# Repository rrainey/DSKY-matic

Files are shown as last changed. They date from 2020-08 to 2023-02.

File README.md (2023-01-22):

# The DSKY-matic Project
A Functioning Apollo DSKY Replica - October 2021

## Introduction

The Apollo Guidance Compuer (AGC) is one of the critical inventions that made the U.S. moon landings possible. AGC's were installed in both the Apollo Command Module and Lunar Module. MIT and NASA archives, as well as important contributions from researchers have given us a rich set of detail about how this computer was constructed.

Space and computer enthusiasts like me from all over the world have enjoyed exploring this work from the early space era.

### Why is this project called "DSKY-matic"?

Because *"Riley Rainey's Apollo Guidance Computer DSKY Replica Project"* doesn't really roll off the tongue.

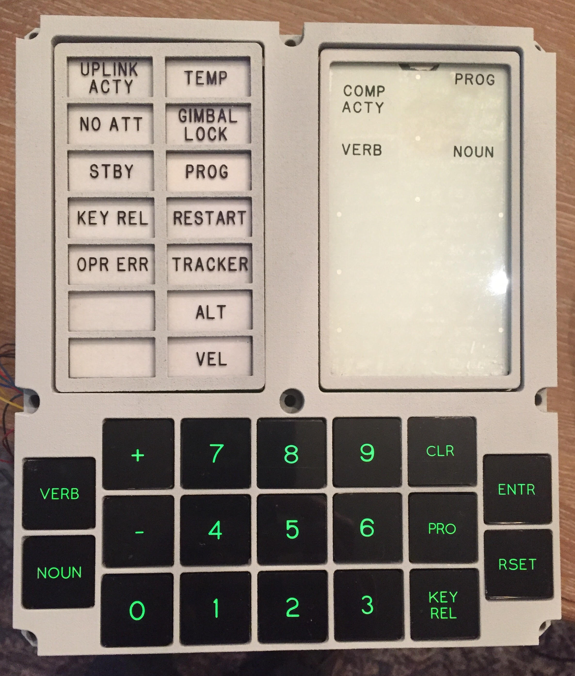
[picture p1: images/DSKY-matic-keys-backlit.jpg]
The first DSKY-matic prototype


Naming a project is often difficult. In this case it's especially hard: the Apollo Guidance Computer has inspired many replica projects. I wanted to create a replica of the DSKY that was faithful to the original look and feel. And I wanted to be able to interact with it.  I came up with **DSKY-matic** to tag it with an easy name distinguishing it from other projects.

DSKY-matic is an open project so that anyone can reproduce the work or build upon my results.

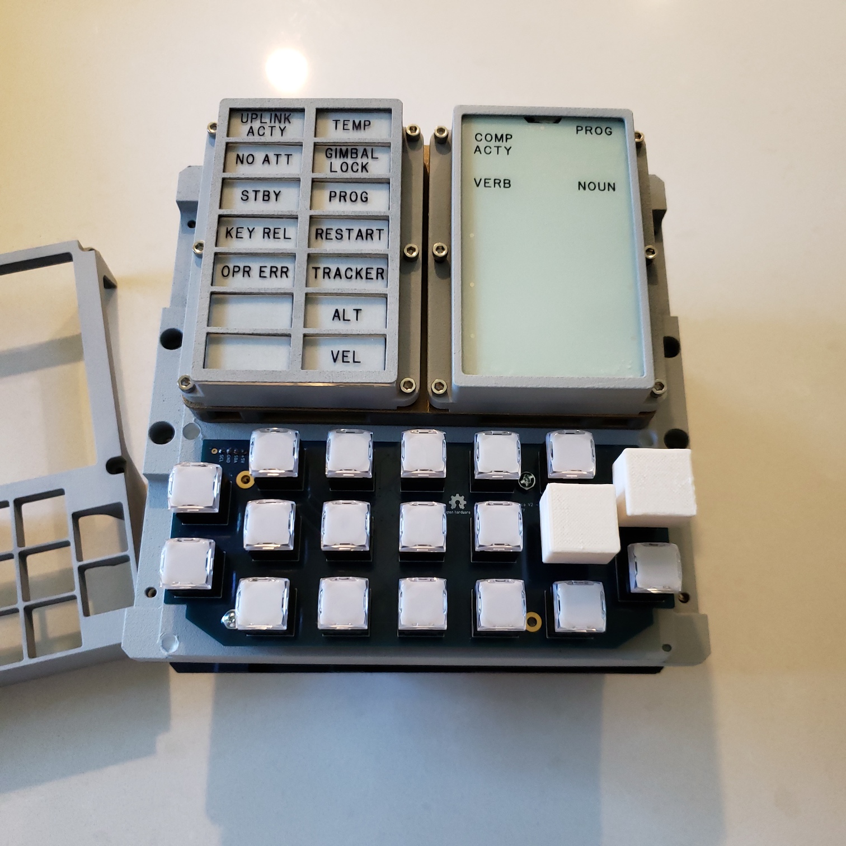
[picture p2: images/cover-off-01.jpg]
The first DSKY-matic prototype (cover off)


### Components and cloning this project

The EL or LED Displays, Alarm Panel, and Keyboard are each modular components. They are driven by a
  Raspberry Pi 4 to simulate the AGC, but each could be swapped out with equivalent redesigns. A
  Power Supply Hat mates with the Raspberry Pi 4 to distribute +5V and +3.3V power to all boards.

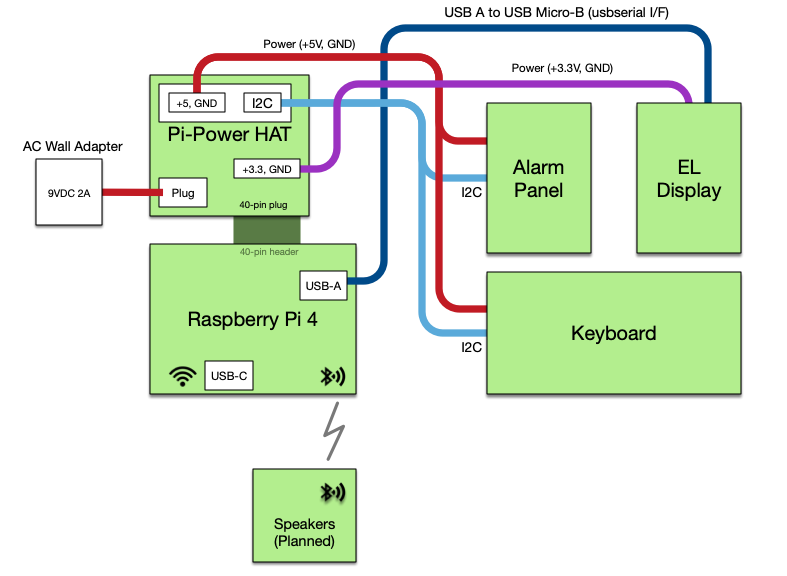
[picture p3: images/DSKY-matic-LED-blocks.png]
The first DSKY-matic prototype


You will find more information about interconnections and cabling in [this document](ASSEMBLY.md)

### Project Status

Hardware work is complete. I'm working on a distributable version of the full simulator software.

Major to-dos:

* [**complete**] adapt Virtual AGC to use these Lamp, Keyboard, and Display drivers
* [**complete**] improve the keyboard's pushbutton design - the current version is a rather clunky 3D printed design that could look much more realistic
* [**complete**] design and test an alternative to the original Electroluminescent Display module. This alternate assembly uses LEDs in place of the EL display.  It's easier to build and may be more reliable over time - if not as cool.
* [**complete**] build and test batch of the revised (current limited) EL Driver boards
* [**complete**] test fully integrated DSKY hardware and software driver configuration
* [**in progress**] Integrated AGC and spacecraft simulator software

### Cloning

The hardware and firmware for each major component is segregated into git submodules. You will need to follow some specific steps to clone the entire tree on your local machine. First, clone this repository:

        $ git clone https://github.com/rrainey/DSKY-matic.git

Go into the project folder:

        $ cd DSKY-matic

Now clone all submodules:

        $ git submodule update --init --recursive --remote

### Directory Structure

* **hardware** - 3D-printable frame components designed using Fusion 360. STEP and the original Fusion source files are provided. Hardware models used in thie replica were derived from models found in the [AGC Mechanical CAD project](https://github.com/rrainey/agc-mechanical-cad).

* **src** - software components designed to run on the project's embedded Raspberry Pi 4.  This software is a Apollo Guidance Computer virtual machine interfacing to the displays and keyboard via I2C and USB serial communications drivers.

* **DSKY-alarm-panel-replica** - definition of the Alarm Panel hardware and software assembly

* **DSKY-digital-indicator-replica** - definition an alternative to the EL Display Panel; this variant is based on LEDs

* **DSKY-keyboard-replica** - definition of the Keyboard hardware and software assembly

* **Pi-Power** - power supply hat for the Raspberry Pi 4

* **virtualagc** - Ron Burkey's Virtual AGC software; runs on the Raspberry Pi 4 in this implementation

## Arduino-based Drivers

The custom hardware boards that are part of this project all run Arduino-based firmware on ATSAMD21 processors.

### Configuring Boards

The peripheral boards for DSKY-matic run Arduino-based software. When you have a board ready for software installation, you'll use the Arduino IDE to build and install the driver onto a board. Custom DSKY-matic Arduino board definitions help with this process.

There's a few steps leading up to this installation that you'll need to follow first:

1. **Build bootloaders for each board** - these bootloaders are used to install Arduino firmware drivers on each board

```
git clone https://github.com/rrainey/uf2-samdx1
cd uf2-samdx1
make BOARD=dskydisplay_led_m0
make BOARD=dskyalarm_m0
make BOARD=dskykeyboard_m0
```

These steps will build bin and uf2 files in a `build` subfolder.

2. **Install the bootloader** - Bootloaders can be installed by following the procedure outlined in this [Adafruit article](https://learn.adafruit.com/how-to-program-samd-bootloaders). The DSKY-matic Keyboard and LED Display boards are equipped with ATSAMD JTAG/SWD connectors.  Those boards can have the bootloader installed directly using a SEGGER J-Link Edu Mini interface as described in the article.  For the Alarm board, I followed Ben's technique of cannibalizing
  the SAMD processor from a Trinket M0 to install on the board.  The advantage there is that the bootloader is already installed.  You can follow that approach as well, or connect the SWD line up directly and program via a SEGGER interface too.

3. **Install the Arduino IDE** -
Install the Arduino IDE. I'm currently using version 1.8.13.

4. **Install the Arduino board definitions** -
These must be installed in your Arduino IDE. An excellent guide to this process is described at this [Adafruit help page](https://learn.adafruit.com/add-boards-arduino-v164/setup). At the point in the steps where you are supplying "Additional Boards Manager URLs" use this URL: `https://github.com/rrainey/ArduinoCore-samd/releases/download/x1.0.0/package_rrainey_dskymatic_index.json`

5. **Connect a board via USB, Build and install the appropriate firmware driver** -- I'll add more detailed instructions here soon, but the firmware is located in the GitHub repo for each board project.

### Sound setup on the Raspberry Pi 4

There's a bit of set up required to play sound from the ALSA drivers. The aplay and
amixer commands are used here to set the volume from the command line:

<pre>
<b>$ aplay -L</b>
null
    Discard all samples (playback) or generate zero samples (capture)
pulse
    Playback/recording through the PulseAudio sound server
sysdefault:CARD=ALSA
    bcm2835 ALSA, bcm2835 ALSA
    Default Audio Device
<b>$ amixer</b>
Simple mixer control 'Master',0
    Capabilities: pvolume pswitch pswitch-joined penum
    Playback channels: Front Left - Front Right
    Limits: Playback 0 - 65536
    Mono:
    Front Left: Playback 65536 [100%] [on]
    Front Right: Playback 65536 [100%] [on]
Simple mixer control 'Capture',0
    Capabilities: cvolume cswitch cswitch-joined penum
    Capture channels: Front Left - Front Right
    Limits: Capture 0 - 65536
    Front Left: Capture 0 [0%] [on]
    Front Right: Capture 0 [0%] [on]
<b>$ amixer controls</b>
numid=4,iface=MIXER,name='Master Playback Switch'
numid=3,iface=MIXER,name='Master Playback Volume'
numid=2,iface=MIXER,name='Capture Switch'
numid=1,iface=MIXER,name='Capture Volume'
<b>$ amixer cset numid=3 50%</b>
numid=3,iface=MIXER,name='Master Playback Volume'
  ; type=INTEGER,access=rw------,values=2,min=0,max=65536,step=1
  : values=32768,32768
</pre>

### Credits

This project would not have been possible without the generous and open work of these projects:

* [The Virtual AGC Project](https://www.ibiblio.org/apollo/) -- Ron Burkey and others have worked for years to build software emulator of the AGC hardware, supporting developments tools, a collection of original NASA and MIT documents, as well as an archive of transcribed original CM and LEM programs.
* [Adafruit Industries](https://www.adafruit.com/) -- Lady Yada and others have produced a great line of hobbyist microcontrollers and supporting programming tools. They deserve your support.
* [The Raspberry Pi Foundation](https://www.raspberrypi.org/about/) -- The Raspberry Pi Foundation is a UK-based charity that is the source fabulous Linux-compatible low-cost computers.

## DSKY-matic License

Software components (everything in "./src") are licensed under the GPL v2. All other elements are covered 
under Creative Commons Attribution/Share-Alike, all text above must be included in any redistribution. See license.txt for additional details.

## My Background

My name is Riley Rainey. I'm a software developer by profession. I spent a number of years building aerospace simulations as my day job.

## Getting Support

There's no official support available, but you can [leave comments or create an issue](https://github.com/rrainey/DSKY-alarm-panel-replica/issues) in this GitHub project.

  
This work is licensed under a [Creative Commons Attribution-ShareAlike 4.0 International License](http://creativecommons.org/licenses/by-sa/4.0/).

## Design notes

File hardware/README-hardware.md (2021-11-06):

## Off-the-shelf Components

Screws, washers, and threaded inserts are used to asseble the DSKY. I have tried to stick with screws similar to those used in the original DSKY.  These will cost more, but add to the realism of the project.  I Ordered these parts from McMaster Carr.

| Description | Part Number | Qty Ordered | Qty Unit |
|---|---|:---:|---|
| Socket Head Screw 10-32 Thread Size, 1-1/2" Long, Partially Threaded | 92185A994 | 1 | Pack of 10 each |
| Retainers for 6-32 Thread Size Captive Panel Screws | 91065A640 | 1 | Pack of 25 each |
| Socket Head Captive Panel Screw 6-32 Thread Size, 3/4" Long | 95966A237 | 12 | 1 each |
| 18-8 Stainless Steel Socket Head Screw 6-32 Thread Size, 1-1/2" Long, Partially Threaded | 92196A157 | 1 | Pack of 100 each |
| 18-8 Stainless Steel Mil. Spec. Washer Passivated, Number 6 Screw Size, NAS 620-C6 | 90945A716 | 1 | Pack of 250 each |
| 18-8 Stainless Steel Mil. Spec. Washer Passivated, Number 4 Screw Size, NAS 620-C4 | 90945A711 | 1 | Pack of 500 each |
| Passivated 18-8 Stainless Steel Phillips Flat Head Screw 82 Degree Countersink, 4-40 Thread, 7/8" Long | 91771A114 | 1 | Pack of 100 each |
| 18-8 Stainless Steel Socket Head Screw 10-32 Thread Size, 1-1/2" Long, Partially Threaded | 92196A277 | 1 | Pack of 50 each |
| 18-8 Stainless Steel Socket Head Screw 6-32 Thread Size, 3/4" Long | 92196A151 | 1 | Pack of 100 each |
| 18-8 Stainless Steel Socket Head Screw 4-40 Thread Size, 3/8" Long | 92196A108 | 1 | Pack of 100 each |
| 18-8 Stainless Steel Socket Head Screw 6-32 Thread Size, 1/2" Long | 92196A148 | 1 | Pack of 100 each |
| Brass Screw-to-Expand Inserts for Plastic, 10-32 Thread Size, 1/4" Installed Length | 92395A224 | 1 | Pack of 25 each |

## Mounting Hardware Parts

Inserts are used with the two mounting base legs and the Pi mounting bracket. I install ultrasonic style inserts using a C-clamp to screw-down each insert into place.

Components can be ordered from Grainger.com:

| Part Description | Grainger SKU | Order Qty | Where Used |
|---|---|:-----:|---|
| M2.5-0.45mm Machine Screw, Pan, Phillips, Property Class 4.8 | 6GE33 |  1  | Pi Bracket (4) |
| Nylon Flat Washer, Plain FastenerFinish, Fits Bolt Sizes M3, 8 mm | 4DAZ2 |  1  | Pi Bracket (4) |
| Round, Spacer, Nylon, Black, 5mm Outside Dia., PK 10 |3ZMR2 | 1 | Pi Bracket (4) |
| Ultrasonic Insert, Tapered, Brass, M2.5 x 0.45mm Internal Thread | 1GRL4 | 1 | Pi Bracket (4) |
| Cylindrical, Socket Head Cap Screw, #8-32, Stainless Steel, 18- | 6XA72 | 1 | DSKY Base (8) |
| Ultrasonic Insert, Straight Flush, Brass, 8-32 Internal Thread Size, | 1GTL3 | 1 | DSKY Base (8) |
| Ultrasonic Insert, Tapered, Brass, 4-40 Internal Thread Size, UNC, 7/32 in Length | 1GPL4 | 1 | Front Cover (10) |
| Ultrasonic Insert, Tapered, Brass, 6-32 Internal Thread Size, UNC, 5/32 in Length | 1GML7 | 1 | Front Cover (8) |

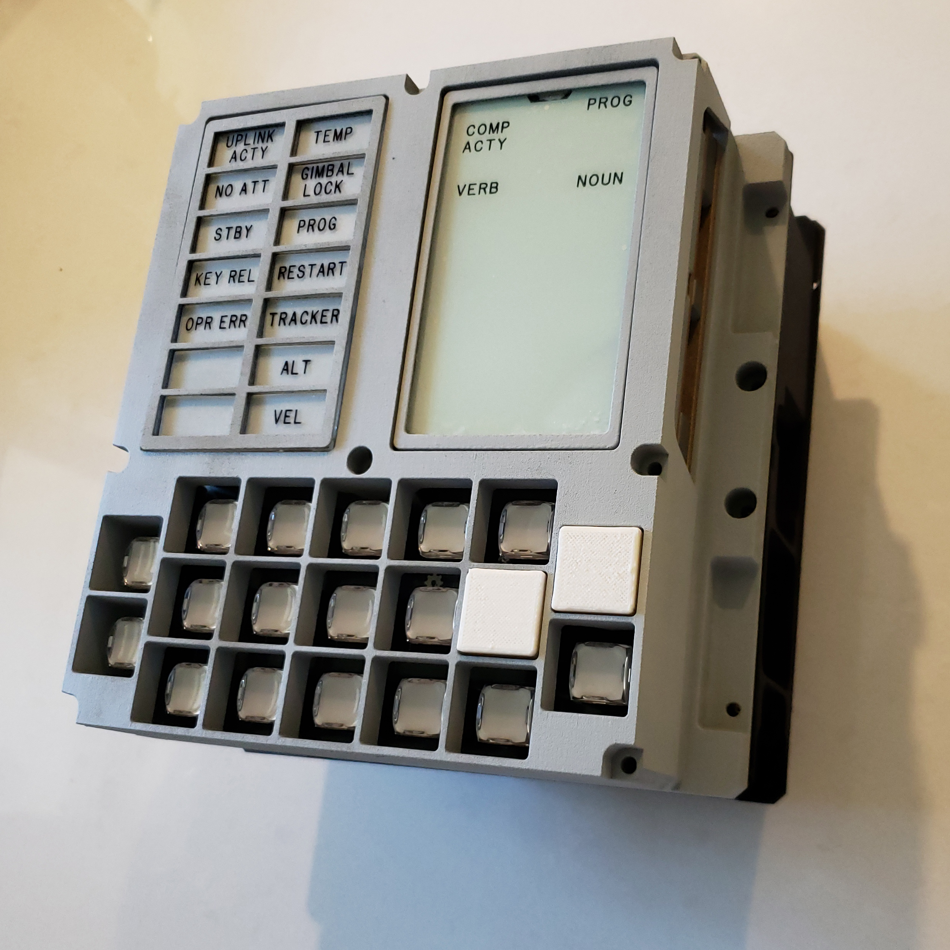
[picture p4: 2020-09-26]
images/oblique-early-large.jpg

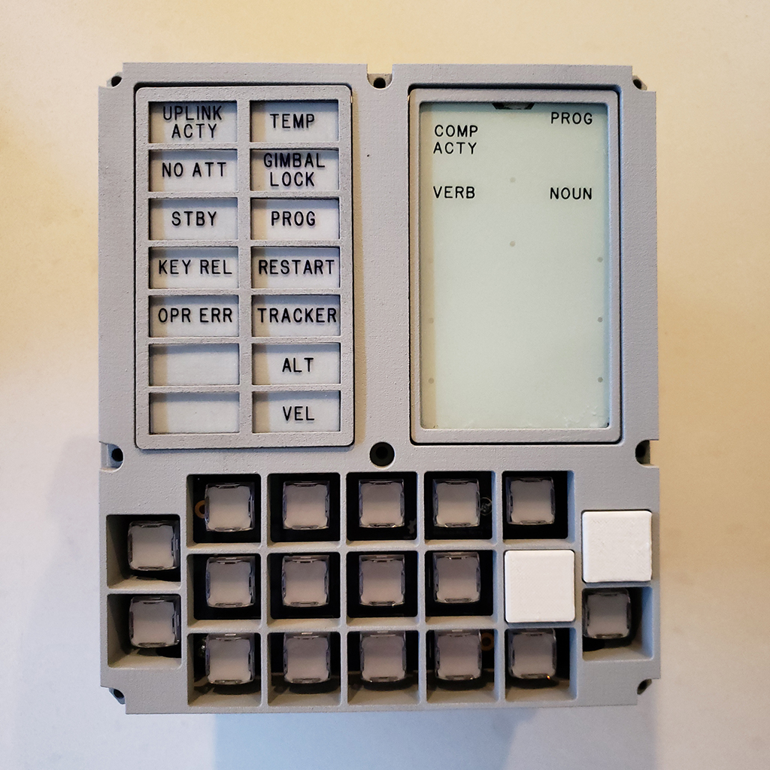
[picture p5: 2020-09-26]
images/front-early-sm.jpg

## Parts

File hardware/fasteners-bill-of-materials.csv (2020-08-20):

Quantity | Unit | Product | Description
1 | Pack of 250 | 90945A716 | 18-8 Stainless Steel Mil. Spec. Washer Passivated, Number 6 Screw Size, NAS 620-C6
1 | Pack of 50 | 92395A112 | Brass Screw-to-Expand Inserts for Plastic, 4-40 Thread Size, 0.188" Installed Length
1 | Pack of 50 | 92395A113 | Brass Screw-to-Expand Inserts for Plastic, 6-32 Thread Size, 1/4" Installed Length
1 | Pack of 25 | 92395A224 | Brass Screw-To-Expand Inserts For Plastic, 10-32 Thread Size, 1/4" Installed Length
1 | Pack of 500 | 90945A711 | 18-8 Stainless Steel Mil. Spec. Washer Passivated, Number 4 Screw Size, NAS 620-C4
1 | Pack of 25 | 91065A640 | Retainers for 6-32 Thread Size Captive Panel Screws
12 | Each | 95966A237 | Socket Head Captive Panel Screw 6-32 Thread Size, 3/4" Long
1 | Pack of 100 | 91771A114 | 18-8 Stainless Steel Phillips Flat Head Screw Passivated, 4-40 Thread Size, 7/8" Long
1 | Pack of 50 | 92196A277 | 18-8 Stainless Steel Socket Head Screw 10-32 Thread Size, 1-1/2" Long, Partially Threaded
1 | Pack of 100 | 92196A151 | 18-8 Stainless Steel Socket Head Screw 6-32 Thread Size, 3/4" Long
1 | Pack of 100 | 92196A108 | 18-8 Stainless Steel Socket Head Screw 4-40 Thread Size, 3/8" Long
1 | Pack of 100 | 92196A148 | 18-8 Stainless Steel Socket Head Screw 6-32 Thread Size, 1/2" Long

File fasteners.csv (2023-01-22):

QTY | UNIT | MCMASTER PRODUCT | DESCRIPTION | UNIT PRICE | EXTENDED PRICE
1 | Pack of 10 each | 92185A994 | Super-Corrosion-Resistant 316 Stainless Steel Socket Head Screw 10-32 Thread Size, 1-1/2" Long, Partially Threaded | 6.13 | 6.13
1 | Pack of 25 each | 91065A640 | Retainers for 6-32 Thread Size Captive Panel Screws | 14.15 | 14.15
12 | Each | 95966A237 | Socket Head Captive Panel Screw 6-32 Thread Size, 3/4" Long | 4.15 | 49.80
1 | Pack of 100 each | 92196A157 | 18-8 Stainless Steel Socket Head Screw 6-32 Thread Size, 1-1/2" Long, Partially Threaded | 17.01 | 17.01
1 | Pack of 250 each | 90945A716 | 18-8 Stainless Steel Mil. Spec. Washer Passivated, Number 6 Screw Size, NAS 620-C6 | 20.21 | 20.21
1 | Pack of 500 each | 90945A711 | 18-8 Stainless Steel Mil. Spec. Washer Passivated, Number 4 Screw Size, NAS 620-C4 | 32.50 | 32.50
1 | Pack of 100 each | 91771A114 | Passivated 18-8 Stainless Steel Phillips Flat Head Screw 82 Degree Countersink, 4-40 Thread, 7/8" Long | 7.59 | 7.59
1 | Pack of 50 each | 92196A277 | 18-8 Stainless Steel Socket Head Screw 10-32 Thread Size, 1-1/2" Long, Partially Threaded | 16.09 | 16.09
1 | Pack of 100 each | 92196A151 | 18-8 Stainless Steel Socket Head Screw 6-32 Thread Size, 3/4" Long | 9.50 | 9.50
1 | Pack of 100 each | 92196A108 | 18-8 Stainless Steel Socket Head Screw 4-40 Thread Size, 3/8" Long | 6.07 | 6.07
1 | Pack of 100 each | 92196A148 | 18-8 Stainless Steel Socket Head Screw 6-32 Thread Size, 1/2" Long | 8.72 | 8.72

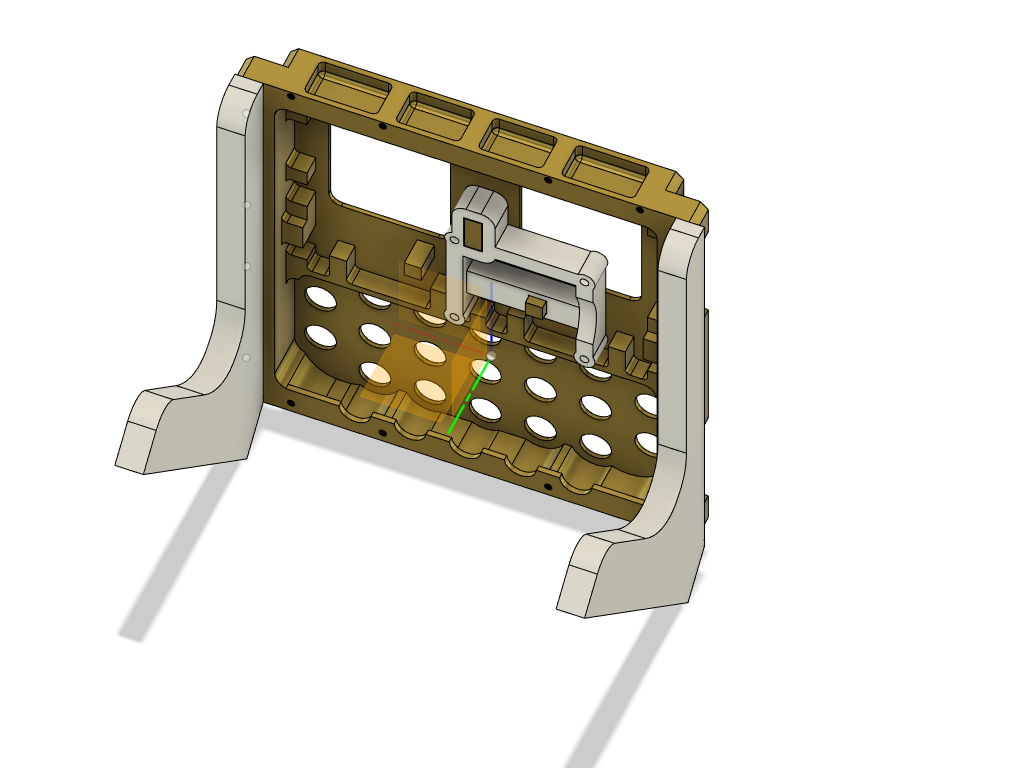
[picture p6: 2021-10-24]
images/Extra-components v18.png

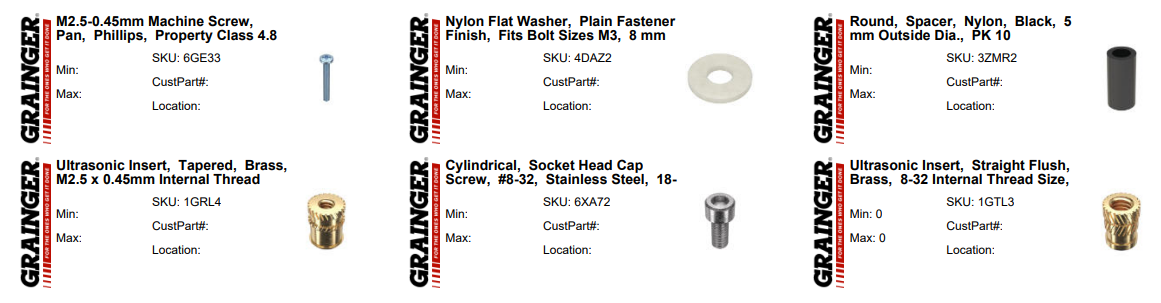
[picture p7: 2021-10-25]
images/extra-hardware-BOM.PNG

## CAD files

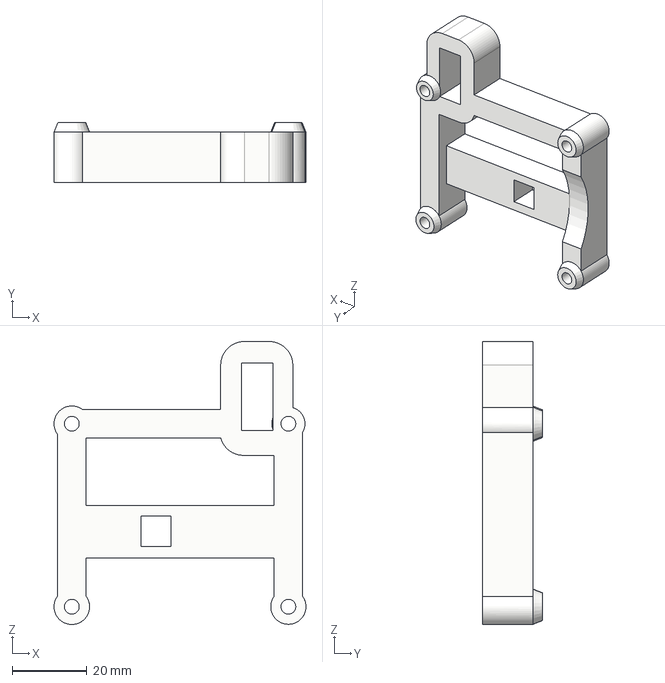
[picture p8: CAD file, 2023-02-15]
hardware/pi-mount.step
67.5 x 16.0 x 75.8 mm

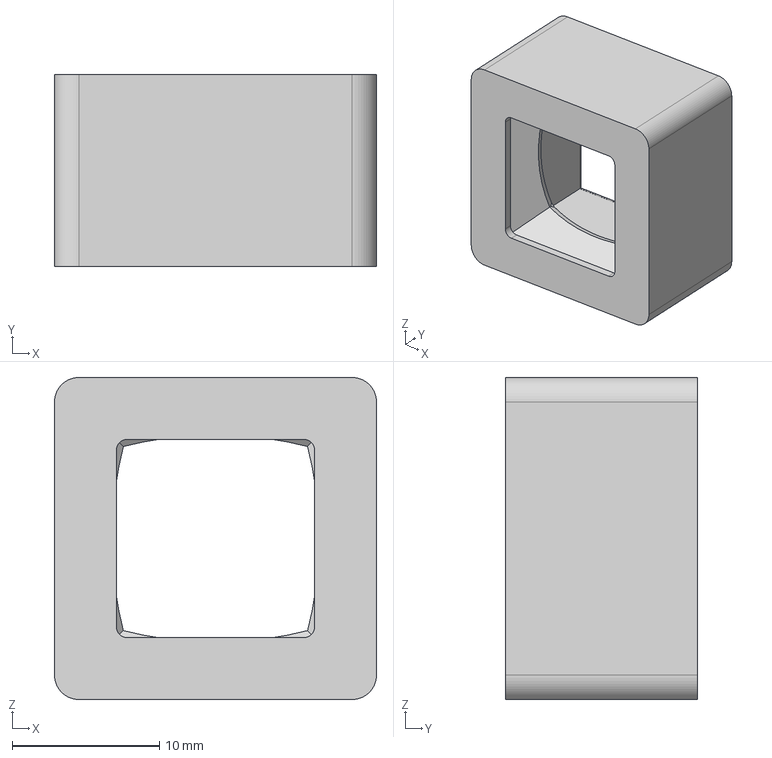
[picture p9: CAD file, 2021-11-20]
hardware/Keycap-base.step
21.8 x 13.0 x 21.8 mm

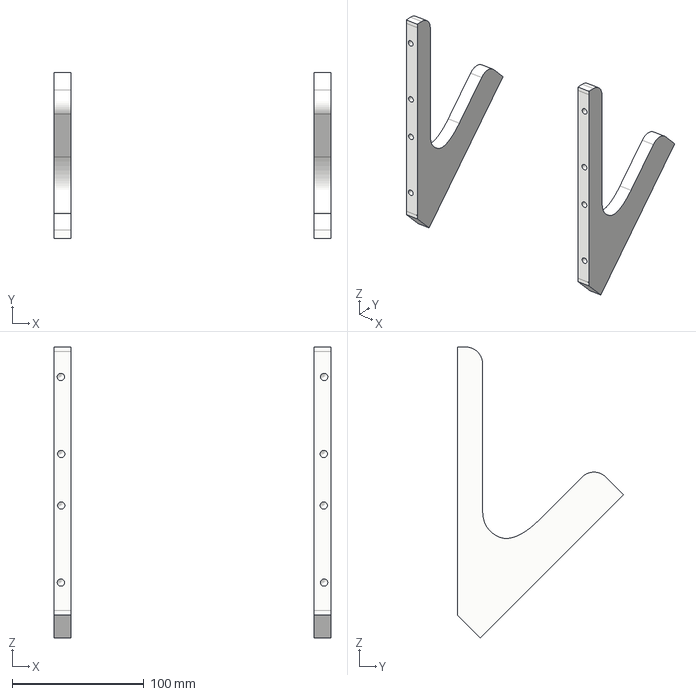
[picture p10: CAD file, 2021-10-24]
hardware/right-base.step
209.7 x 125.9 x 220.5 mm

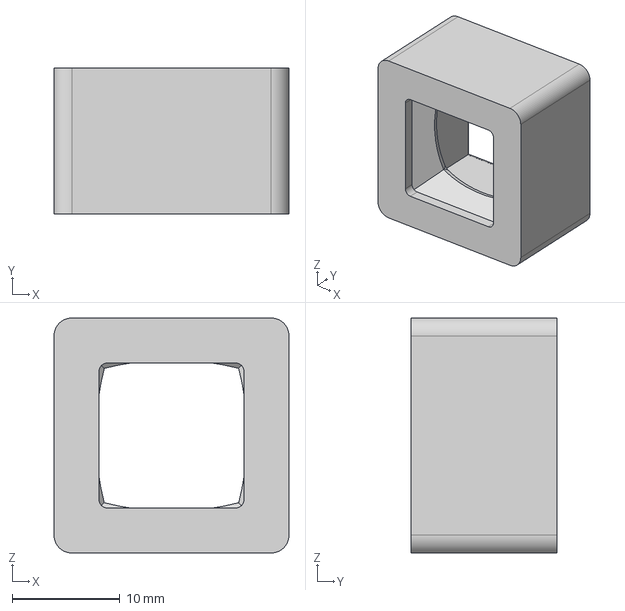
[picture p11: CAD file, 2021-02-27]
hardware/Keycap-on-keycap.step
21.8 x 13.6 x 21.8 mm

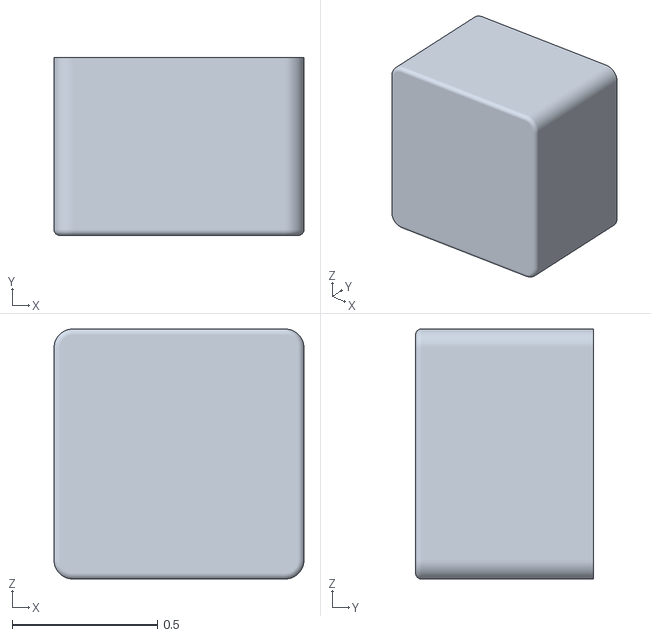
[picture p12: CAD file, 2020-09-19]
hardware/Keycap.stl
0.86 x 0.612 x 0.86

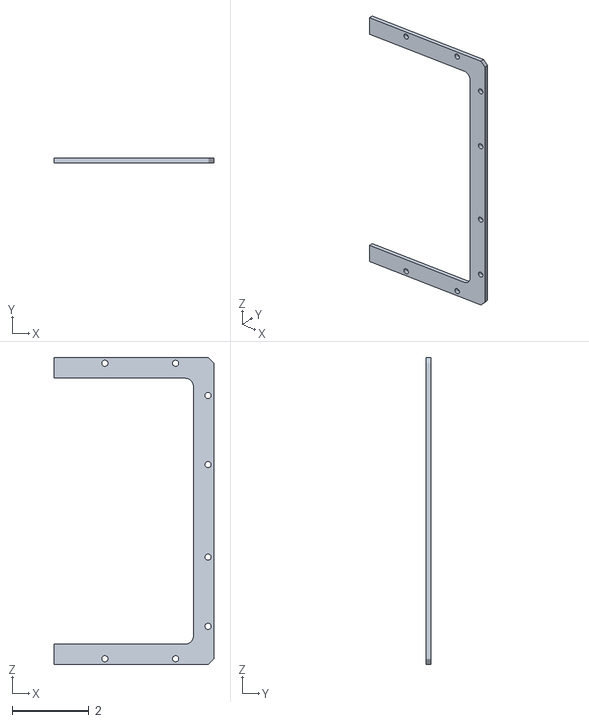
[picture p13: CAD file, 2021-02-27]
hardware/optimized-small/1006349-Right-half.stl
4.16 x 0.125 x 7.99

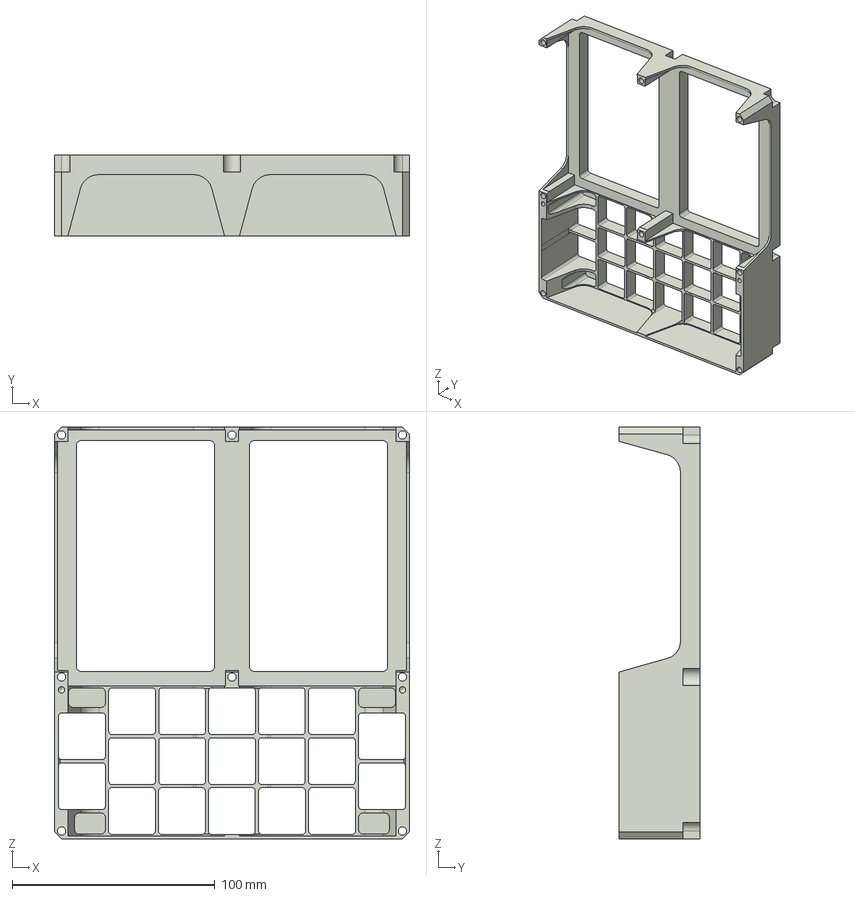
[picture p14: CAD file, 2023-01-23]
hardware/2004929-exact-COVER, FRONT.step
175.3 x 39.9 x 203.2 mm

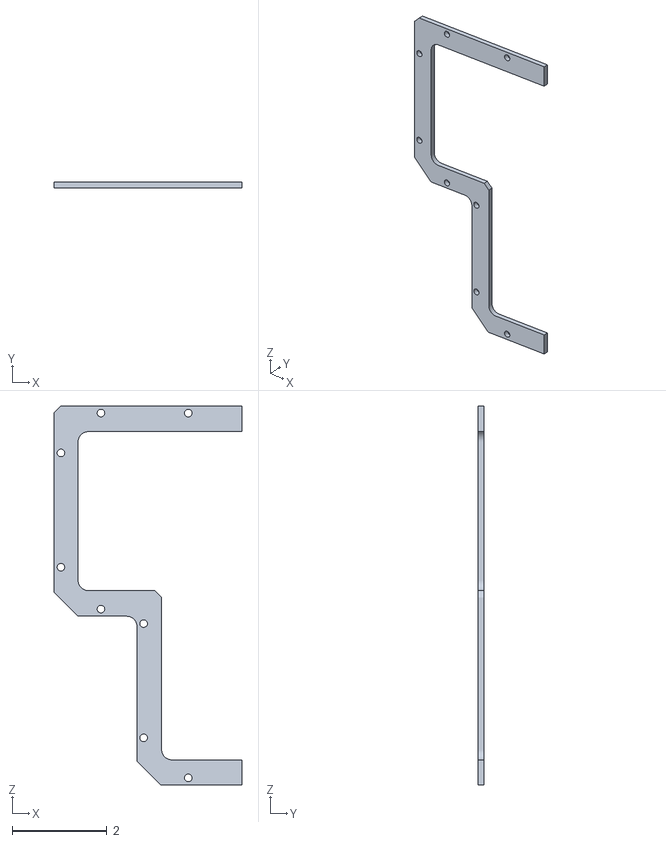
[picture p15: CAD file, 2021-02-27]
hardware/optimized-small/1006349-Left-half.stl
3.96 x 0.125 x 7.99

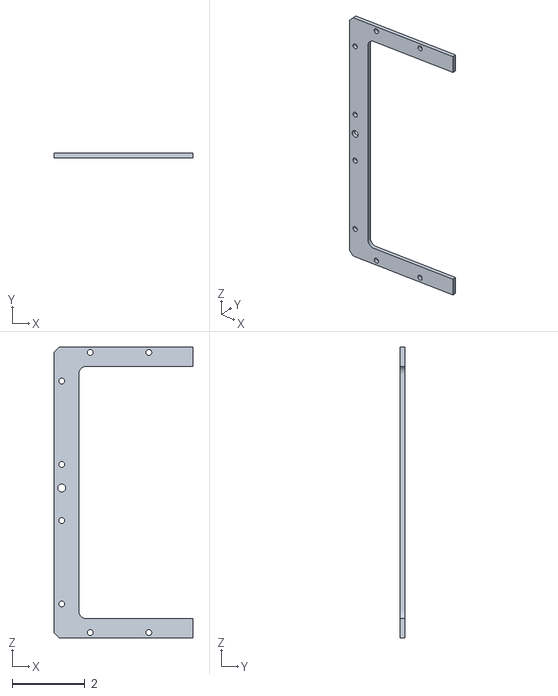
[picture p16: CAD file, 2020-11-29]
hardware/optimized-small/1006350A-Left-half.stl
3.82 x 0.125 x 8.00

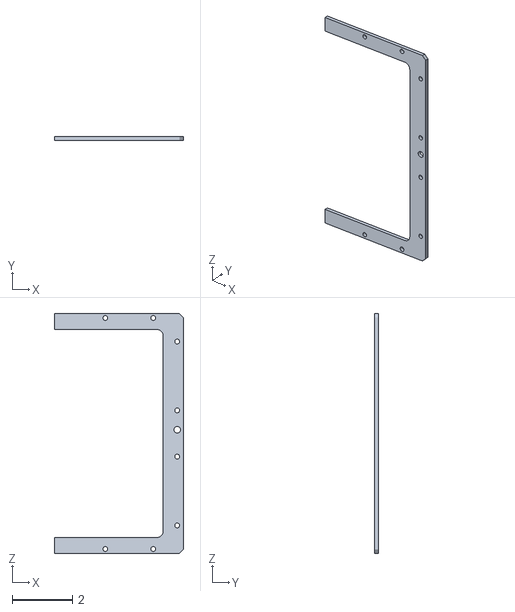
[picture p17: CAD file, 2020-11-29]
hardware/optimized-small/1006350A-Right-half.stl
4.30 x 0.125 x 8.00

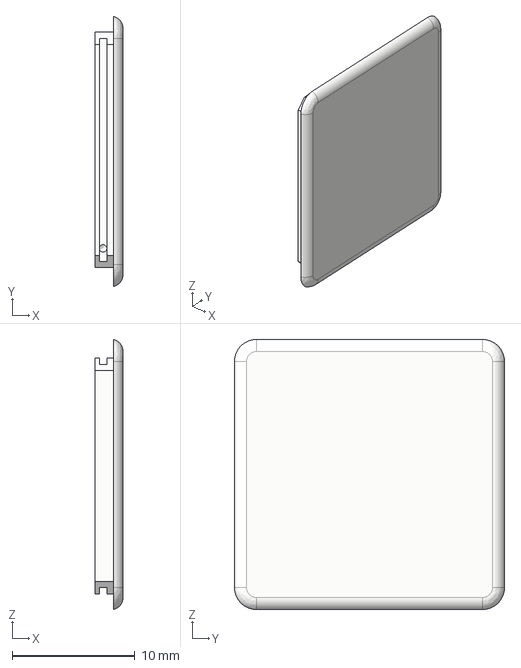
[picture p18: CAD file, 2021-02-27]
hardware/1006353A-exact-CAP.step
2.29 x 22.0 x 22.0 mm

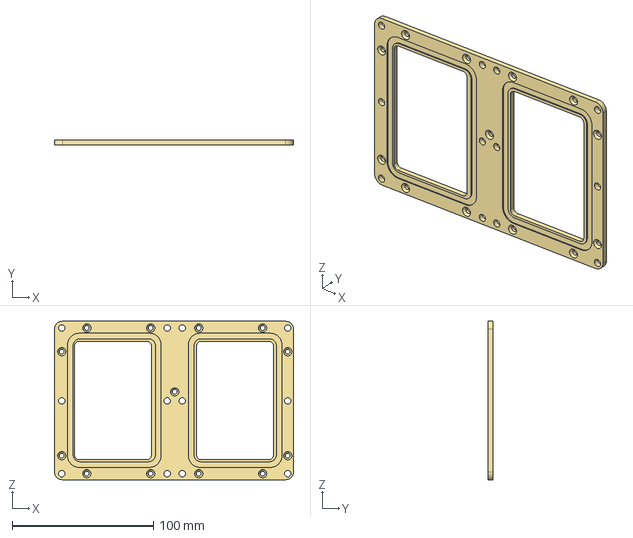
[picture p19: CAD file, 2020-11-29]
hardware/1006351A-exact-GASKET.step
169.2 x 3.20 x 112.3 mm

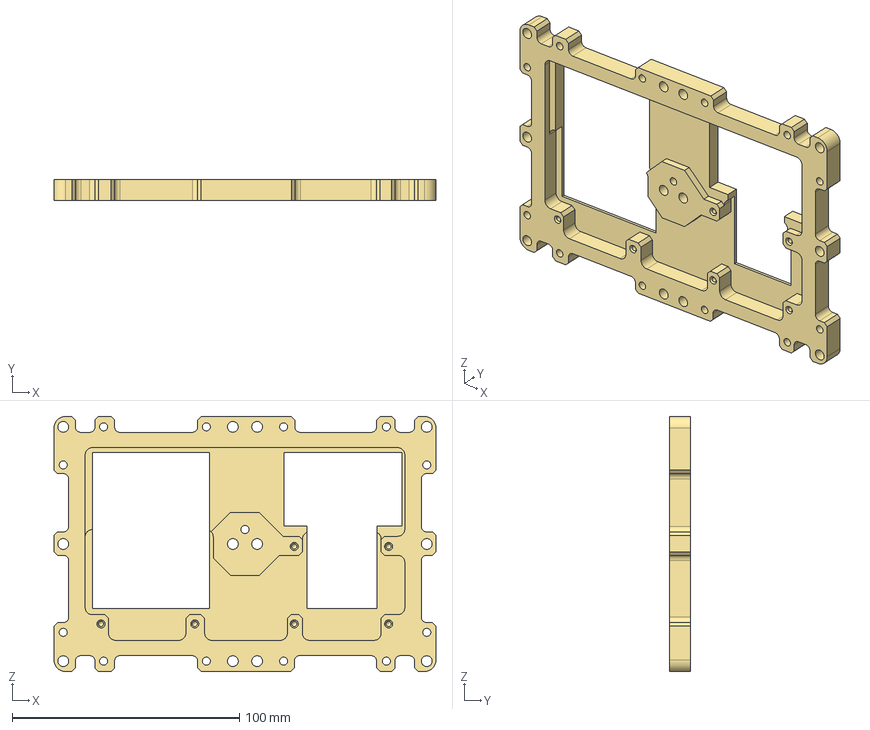
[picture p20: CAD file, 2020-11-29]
hardware/2004919E-inserts-PLATE, ADAPTER.step
168.1 x 9.14 x 112.3 mm

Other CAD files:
hardware/left-base.step
hardware/1006351A-exact-GASKET.f3d
hardware/Keycap-base.stl
hardware/optimized-small/1006349-3dprint-GASKET, RETAINED.f3d
hardware/optimized-small/1006350A-3dprint-GASKET, RETAINED.f3d

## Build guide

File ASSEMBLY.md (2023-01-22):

## Board Cabling

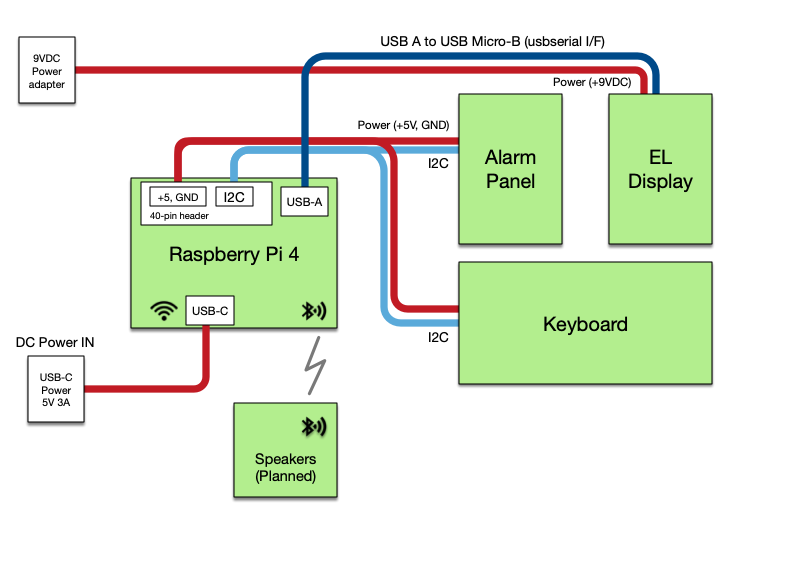
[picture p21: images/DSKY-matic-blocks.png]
The first DSKY-matic prototype


### Four-wire Interconnections

A simple four-wire bus is used to interconnect the Raspberry Pi Power daughter board, the Keyboard assembly, and the Alarm Panel assembly.

| Signal | Insulator Color |
| --- | ---  |
| +5VDC | RED |
| Ground | GREEN |
| I2C Data (SDA)  | BLUE |
| I2C Clock (SCL) | YELLOW |

Because of the small clearances at the Keyboard once installed, I find it easier to solder two sets of these four wire groups to the keyboard and then route one set to the Pi and one set to the Alarm Panel assembly.

### Display Assembly connections

Your choice of the EL or LED Display Panel assembly both connect in a different way: data is passed via a USB-A to USB-Micro-B cable.  Separate power is supplied by a +3.3V/GND pair originating at the Pi-Power daughter board for the Raspberry Pi.  This separate source is required as the Raspberry Pi USB connection is unable to supply sufficient current for some operating conditions.

## 3D Printing Components

How can you get the best results 3D printing the hardware components?  Of available 3D printing technologies, I find that Selective Laser Sintering (SLS) of the parts in Nylon 12 gives -- by far -- the best results for the price.  Nearly all parts in my project were printed in this manner.  I farmed out my SLS printing to [Xometry](https://www.xometry.com/) for this project.

### Bill Of Materials

| Order Qty | Part | 3D Print Process |
|----| --- | ---  |
|1| [2004918B-inserts-HOUSING, FRONT](https://github.com/rrainey/DSKY-matic/blob/master/hardware/2004918B-inserts-HOUSING%2C%20FRONT.step)  | SLS |
|1| [2004929-exact-COVER, FRONT](https://github.com/rrainey/DSKY-matic/blob/master/hardware/2004929-exact-COVER%2C%20FRONT.step) | SLS |
|1| [2004919E-inserts-PLATE, ADAPTER](https://github.com/rrainey/DSKY-matic/blob/master/hardware/2004919E-inserts-PLATE%2C%20ADAPTER.step)  | SLS |
|2| [1006351A-exact-GASKET](https://github.com/rrainey/DSKY-matic/blob/master/hardware/1006351A-exact-GASKET.step)  | SLS |
|1| [Alarm Panel replica assembly](https://github.com/rrainey/DSKY-alarm-panel-replica) | - |
|1| [Keyboard replica assembly](DSKY-keyboard-replica) | - |
|1| [EL Display replica assembly](https://github.com/rrainey/DSKY-digital-indicator-replica) | - |
|1| [Pi-Power daughter board assembly](https://github.com/rrainey/Pi-Power) | - |
|1| [Raspberry Pi Mount](https://github.com/rrainey/DSKY-matic/blob/master/hardware/pi-mount.step) | SLS, PLA, or ABS |
|1| [Display base, left arm](https://github.com/rrainey/DSKY-matic/blob/master/hardware/left-base.step) | SLS, PLA, or ABS |
|1| [Display base, right arm](https://github.com/rrainey/DSKY-matic/blob/master/hardware/right-base.step) | SLS, PLA, or ABS |
|1| [Power Supply Module, 100-240V 50/60Hz, Output: 9V@3.5A; TRIAD P/N: WSU090-3500](https://github.com/rrainey/DSKY-matic/blob/master/hardware/right-base.step) | - |
|1| [Raspberry Pi 4B 4 or 8GB](https://www.raspberrypi.com/products/raspberry-pi-4-model-b/) | - |
|1| [Insert: 4-40 Internal Thread Size, Item # 1GPL4 (package of 100)](https://www.grainger.com/product/GRAINGER-APPROVED-Ultrasonic-Insert-4-40-Internal-1GPL4) | - |
|1| [Insert: M2.5 Internal Thread Size, Item # 1GRL4 (package of 100)](https://www.grainger.com/product/GRAINGER-APPROVED-Ultrasonic-Insert-M2-5-x-0-1GRL4) | - |

NOTE: This BOM is currently incomplete, it does not list all required cable assemblies, inserts, or fasteners.
A current McMaster/Carr fastener shopping list can be found in [fasteners.csv](fasteners.csv)

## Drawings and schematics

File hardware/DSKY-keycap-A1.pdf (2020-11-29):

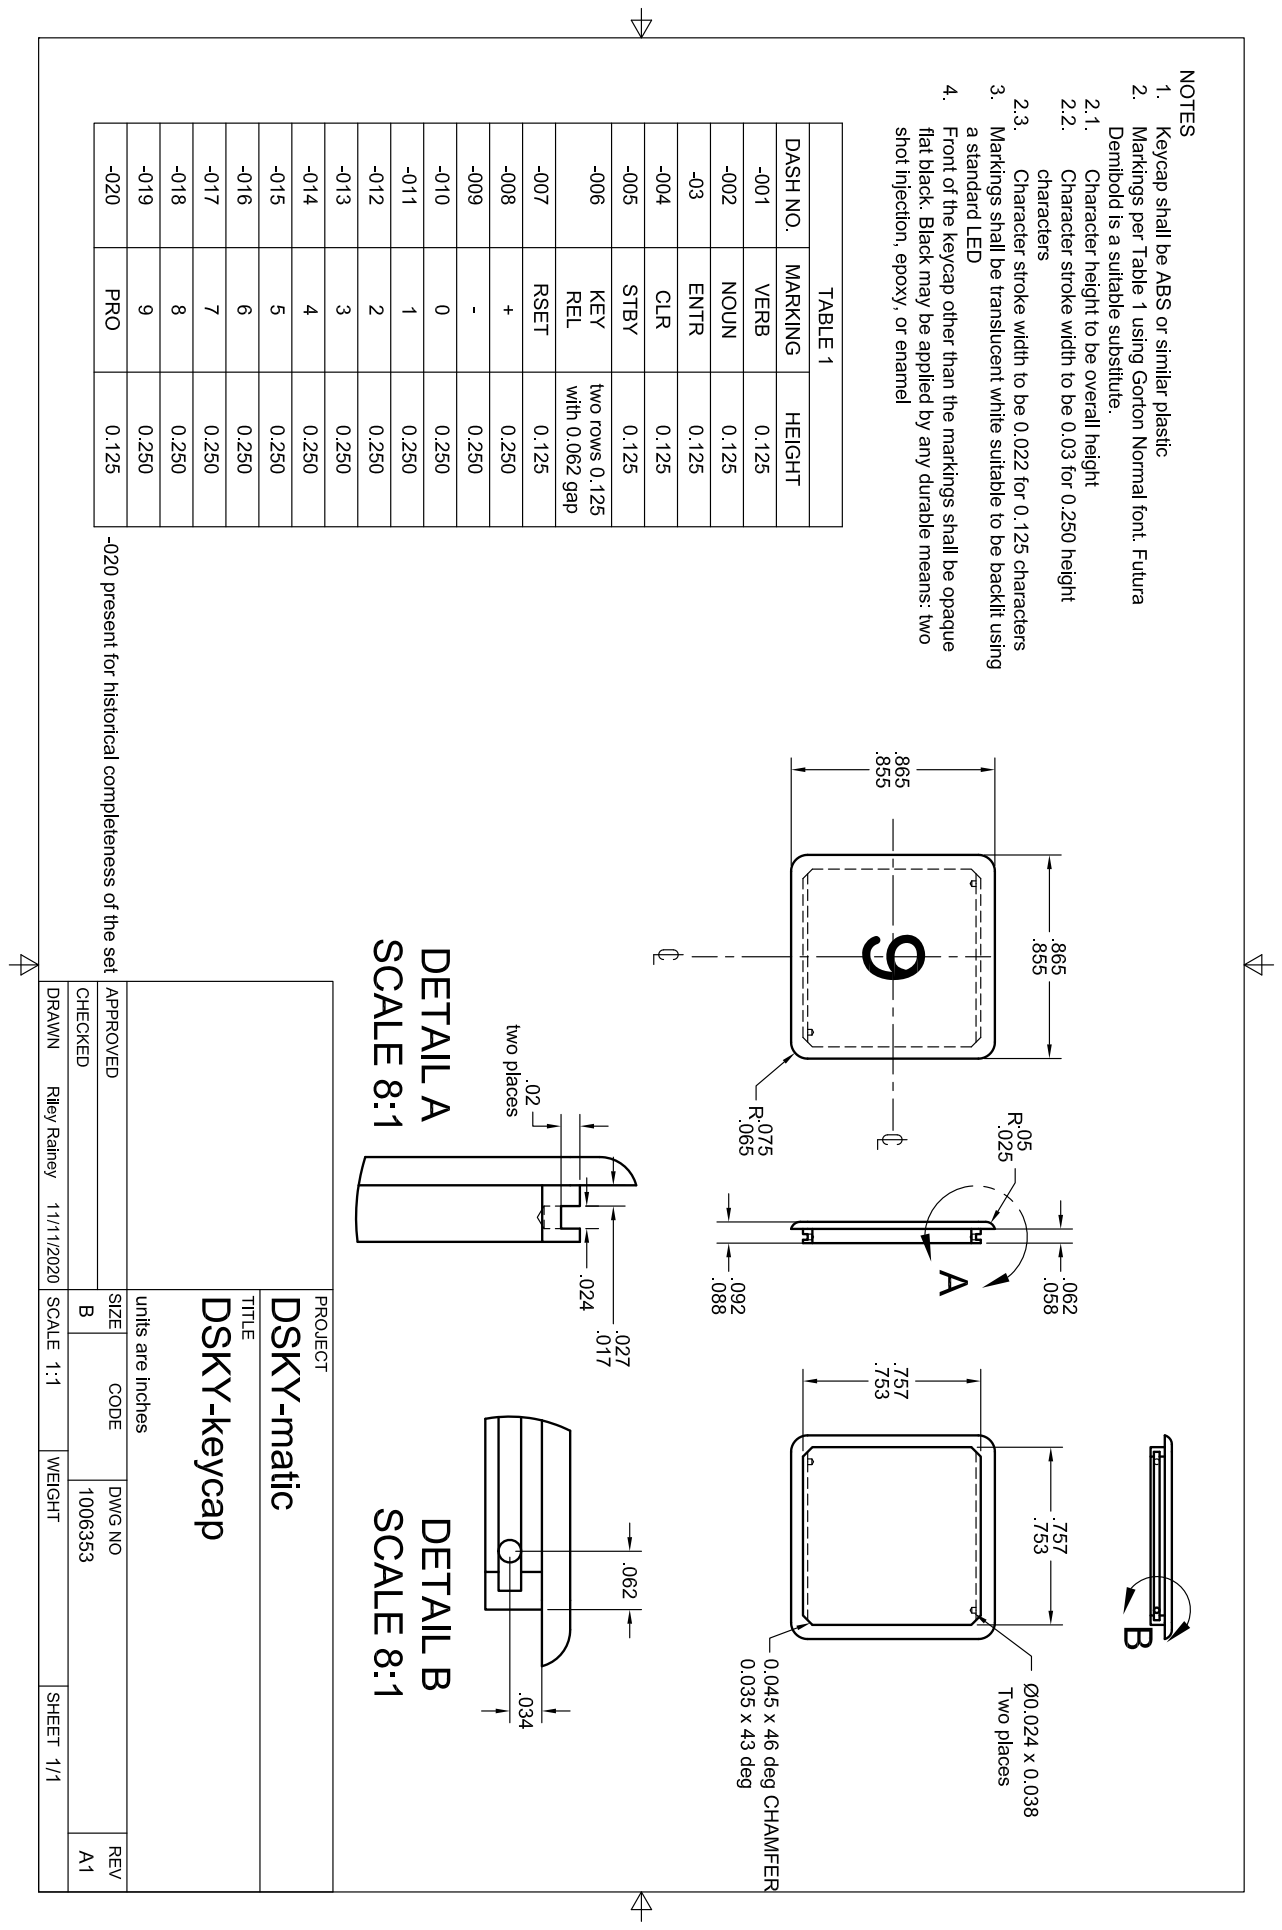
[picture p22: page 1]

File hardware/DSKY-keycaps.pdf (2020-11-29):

## VERB

## ENTR

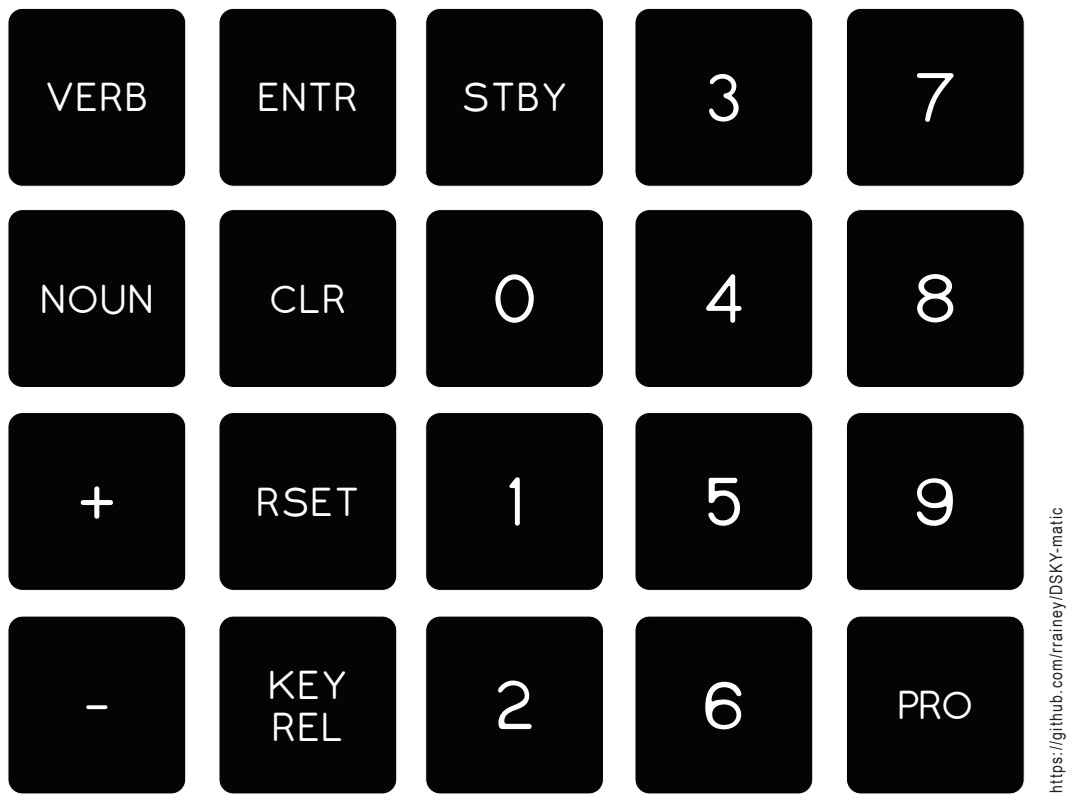
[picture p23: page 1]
NOUN +-; CLR; RSET; KEY REL; STBY 012; PRO

https://github.com/rrainey/DSKY-matic

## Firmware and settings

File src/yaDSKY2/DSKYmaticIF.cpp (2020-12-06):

/*
 * DSKY-matic driver interface for Raspberry Pi OS
 * 
 * Copyright (c) 2020, Riley Rainey
 * 
 * This file is part of the DSKY-matic project. All software in that project
 * is release via the GPL v2 license. See src/SOFTWARE-LICENSE.txt. Hardware and 
 * artistic elements are covered by a separate CC-BY-SA license. 
 *
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
 * You should have received a copy of the GNU General Public License
 * along with DSKY-matic; if not, write to the Free Software
 * Foundation, Inc., 59 Temple Place, Suite 330, Boston, MA  02111-1307  USA
 */

#include "ChannelQueue.h"
#include "DSKYmaticIF.h"

#include <unistd.h>
#include <fcntl.h>
#include <termios.h>
#include <sys/ioctl.h>
#include <sys/types.h>
#include <sys/socket.h>
#include <errno.h>
#include <linux/i2c-dev.h>

#include <string>
#include <cstring>
#include <memory>

#include "../yaAGC/yaAGC.h"
#include "../yaAGC/agc_engine.h"

#include "yaDSKY2.h"
MainFrame * MainFrame;

struct _keyInfo {
    const char * name;
    int outputCode;
};

/**
 * Key event codes passed to us the keyboard I2C interface
 */
static struct _keyInfo keyMap[] = {
    { NULL, 0}, // entry 0 does not correspond to an S-key.
    {"STBY/PRO", 99},
    {"KEY REL", 25},
    {"ENTR", 28},
    {"VERB", 17},
    {"NOUN", 31},
    {"CLR", 30},
    {"(minus)", 27},
    {"0", 16},
    {"(plus)", 26},
    {"1", 1},
    {"2", 2},
    {"3", 3},
    {"4", 4},
    {"5", 5},
    {"6", 6},
    {"7", 7},
    {"8", 8},
    {"9", 9},
    {"RESET", 18}
};

struct _ch010CodeToDigitMap {
  unsigned char code;
  char value;
};

static struct _ch010CodeToDigitMap digitMap[] = {
  {0,  ' '},
  {21, '0'},
  {3,  '1'},
  {25, '2'},
  {27, '3'},
  {15, '4'},
  {30, '5'},
  {28, '6'},
  {19, '7'},
  {29, '8'},
  {31, '9'}
};

/*
 * See https://www.ibiblio.org/apollo/developer.html
 * for documentation of Channel 010 codes
 */
struct _ch010CodeToELDriver {
  unsigned char code;     // Code sent from Output Channel 010 directive
  unsigned char value;    // Value to be sent to DSKY Driver
};

/**
 * Map AGC-native channel key codes to EL Driver seven segment commands
 * The original DSKY interface actually defines 32 distinct codes -- not just ten decimal digits --
 * all are reproduced here.
 */
struct _ch010CodeToELDriver ch010CodeToSegmentMap[32] = {
    {0, 0},
    {1, SEGMENT_b },
    {2, SEGMENT_c },
    {3, SEGMENT_b | SEGMENT_c },
    {4, SEGMENT_c | SEGMENT_f },
    {5, SEGMENT_b | SEGMENT_c | SEGMENT_f },
    {6, SEGMENT_c | SEGMENT_f },
    {7, SEGMENT_b | SEGMENT_c | SEGMENT_f },
    {8, SEGMENT_g },
    {9, SEGMENT_b | SEGMENT_g },
    {10, SEGMENT_c | SEGMENT_g },
    {11, SEGMENT_b | SEGMENT_c | SEGMENT_g },
    {12, SEGMENT_c | SEGMENT_f | SEGMENT_g },
    {13, SEGMENT_b | SEGMENT_c | SEGMENT_f | SEGMENT_g },
    {14, SEGMENT_c | SEGMENT_f | SEGMENT_g },
    {15, SEGMENT_b | SEGMENT_c | SEGMENT_f | SEGMENT_g },
    {16, SEGMENT_a | SEGMENT_e },
    {17, SEGMENT_a | SEGMENT_b | SEGMENT_e },
    {18, SEGMENT_a | SEGMENT_c },
    {19, SEGMENT_a | SEGMENT_b | SEGMENT_c },
    {20, SEGMENT_a | SEGMENT_c | SEGMENT_d | SEGMENT_e | SEGMENT_f  },
    {21, SEGMENT_a | SEGMENT_b | SEGMENT_c | SEGMENT_d | SEGMENT_e | SEGMENT_f  },
    {22, SEGMENT_a | SEGMENT_c | SEGMENT_d | SEGMENT_f },
    {23, SEGMENT_a | SEGMENT_b | SEGMENT_c | SEGMENT_d | SEGMENT_f },
    {24, SEGMENT_a | SEGMENT_d | SEGMENT_e | SEGMENT_g },
    {25, SEGMENT_a | SEGMENT_b | SEGMENT_d | SEGMENT_e | SEGMENT_g },
    {26, SEGMENT_a | SEGMENT_c | SEGMENT_d | SEGMENT_g },
    {27, SEGMENT_a | SEGMENT_b | SEGMENT_c | SEGMENT_d | SEGMENT_g },
    {28, SEGMENT_a | SEGMENT_c | SEGMENT_d | SEGMENT_e | SEGMENT_f | SEGMENT_g },
    {29, SEGMENT_a | SEGMENT_b | SEGMENT_c | SEGMENT_d | SEGMENT_e | SEGMENT_f | SEGMENT_g },
    {30, SEGMENT_a | SEGMENT_c | SEGMENT_d | SEGMENT_f | SEGMENT_g },
    {31, SEGMENT_a | SEGMENT_b | SEGMENT_c | SEGMENT_d | SEGMENT_f | SEGMENT_g }

};

static int StartupDelay ;
static int DebugCounterMode;
static int DebugCounterReg, DebugCounterInc, DebugCounterWhich;
// TestUplink is set when we want to test the digital uplink by emitting
// keycodes on the digital uplink rather than on the DSKY channels.
static int TestUplink;
static int ServerSocket;
static bool ProceedPressed;
static int IoErrorCount, Last11;

DSKYmaticIF::DSKYmaticIF() {

  fdAlarm = -1;
  fdELDisplay = -1;
  fdKeyboard = -1;

  // initialize EL Display Segment map to enable the
  // direct control of each segment in the seven segment display (with all segments initially off)
  unsigned char init = DIGIT_RAW_SEGMENT_CONTROL;

  memset(&ch010Values, 0, sizeof(ch010Values));

  memset(prog, init, 2);
  memset(noun, init, 2);
  memset(verb, init, 2);
  memset(upper, init, 5);
  memset(middle, init, 5);
  memset(lower, init, 5);

  s1placeholder = init;
  s2placeholder = init;
  s3placeholder = init;

  lampState = 0;
  lampStateDirty = true;
  elDisplayStateDirty = true;
  relayTripCount = 0;

  compActyLamp = false;

  flashNounVerb = false;
  flashState = true;
  flashCountdown_ms = 750;
  reported2 = false;
}

void DSKYmaticIF::updateFlashingState(int elapsed_ms) {

  flashCountdown_ms -= elapsed_ms;

  if (flashCountdown_ms <=0) {
    flashCountdown_ms = 750 + flashCountdown_ms;
    flashState = !flashState;

    // TODO: track number of relays affected by each transition.
    // "punt" for now, assuming the NOUN and VERB digits would
    // be illuminated:
    relayTripCount += 14;
  }
}

void DSKYmaticIF::updateAlarmStatusPanel() {
  if (lampStateDirty && fdAlarm >= 0) {
    sendLampState(lampState);
    lampStateDirty = false;
  }
}

bool DSKYmaticIF::sendLampState(unsigned int state) {
  char buf[2];
  bool status = true;

  /*
   * Inhibit any flashing lamps marked for illumination
   */
  if (!flashState) {
    state &= ~(LAMP_KEY_REL | LAMP_OPR_ERR);
  }

  buf[0] = (state >> 8) & 0xff;
  buf[1] = (state & 0xff);
  if (write(fdAlarm, buf, 2) != 2) {
    status = false;
  }
  return status;
}

bool DSKYmaticIF::checkKeyEvent(
    unsigned long *millis,
    unsigned char *s_id,
    unsigned char *state) {
  unsigned char buf[6];
  *millis = 0;
  *s_id = 0;
  *state = 0;
  bool status = false;

  if (read(fdKeyboard, buf, 6) == 6) {
    *millis = (buf[0] << 24) | (buf[1] << 16) | (buf[2] << 8) | buf[3];
    //fprintf(stderr, "%ul\n", *millis);
    *s_id = buf[4];
    *state = buf[5];
    status = true;
  }
  return status;
}
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

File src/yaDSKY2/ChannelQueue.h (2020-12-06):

/*
 * DSKY-matic driver interface for Raspberry Pi OS
 * 
 * Copyright (c) 2020, Riley Rainey
 * 
 * This file is part of the DSKY-matic project. All software in that project
 * is release via the GPL v2 license. See src/SOFTWARE-LICENSE.txt. Hardware and 
 * artistic elements are covered by a separate CC-BY-SA license. 
 *
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
 * You should have received a copy of the GNU General Public License
 * along with DSKY-matic; if not, write to the Free Software
 * Foundation, Inc., 59 Temple Place, Suite 330, Boston, MA  02111-1307  USA
 */

#include <list>

class ChannelIOOperation {
public:
    ChannelIOOperation( unsigned short usChannel, 
                        unsigned short usValue,
                        unsigned short usMask = 077777 )
    {
        m_usChannel = usChannel;
        m_usValue = usValue;
        m_usMask = usMask;
    }

    unsigned short m_usChannel;
    unsigned short m_usValue;
    unsigned short m_usMask;
};

typedef std::list<ChannelIOOperation>   ChannelIOList;

extern ChannelIOList g_AGCChannelOutputQueue;
extern ChannelIOList g_AGCChannelInputQueue;

// Channel definitions from Delco Electronics, Apollo 15 CM SOFTWARE Manual
// Colossus 3 (ARTEMIS 72) Software Description

/**
 * CHANNEL WORD BIT NUMBERS
 */
#define BIT16  0100000
#define BIT15  040000
#define BIT14  020000
#define BIT13  010000
#define BIT12  004000
#define BIT11  002000
#define BIT10  001000
#define BIT9   000400
#define BIT8   000200
#define BIT7   000100
#define BIT6   000040
#define BIT5   000020
#define BIT4   000010
#define BIT3   000004
#define BIT2   000002
#define BIT1   000001

// see https://www.ibiblio.org/apollo/developer.html

#define CH010_OPERATION_MASK        (15<<11)
#define CH010_OPERATION_M1M2        (11<<11)
#define CH010_OPERATION_V1V2        (10<<11)
#define CH010_OPERATION_N1N2        (9<<11)
#define CH010_OPERATION_DIGIT11     (8<<11)
#define CH010_OPERATION_DIGIT1213   (7<<11) //1+ in BIT11
#define CH010_OPERATION_DIGIT1415   (6<<11) //1- in BIT11
#define CH010_OPERATION_DIGIT2122   (5<<11) //2+ in BIT11
#define CH010_OPERATION_DIGIT2324   (4<<11) //2- in BIT11
#define CH010_OPERATION_DIGIT2531   (3<<11) 
#define CH010_OPERATION_DIGIT3233   (2<<11) //3+ in BIT11
#define CH010_OPERATION_DIGIT3435   (1<<11) //3- in BIT11
#define CH010_OPERATION_LAMPS       (12<<11)
#define CH010_PRIO_DISP_LAMP        BIT1
#define CH010_NO_DAP_LAMP           BIT2
#define CH010_VEL_LAMP              BIT3
#define CH010_NO_ATT_LAMP           BIT4
#define CH010_ALT_LAMP              BIT5
#define CH010_GIMBAL_LOCK_LAMP      BIT6
#define CH010_TRACKER_LAMP          BIT8
#define CH010_PROG_LAMP             BIT9
#define CH010_CCCCC_VALUE(x)        (((x) & (0x1F << 5)>> 5)
#define CH010_DDDDD_VALUE(x)        ((x) & 0x1F)

/*
 * From https://www.ibiblio.org/apollo/Documents/agc_programming_info.pdf
 */

#define CH011_ISS_WARNING            0x001
#define CH011_COMP_ACTY_LAMP         0x002
#define CH011_UPLINK_ACTY_LAMP       0x004
#define CH011_TEMP_CAUTION           0x008
#define CH011_KEYBOARD_RELEASE_LAMP  0x010   // flashes at 1.5 CPS
#define CH011_FLASH_VERB_NOUN_LAMPS  0x020   // flashes at 1.5 CPS see https://www.ibiblio.org/apollo/Documents/acelectroniclmma00acel_0.pdf
#define CH011_OPER_ERROR_LAMP        0x040   // flashes at 1.5 CPS

/**
 * S-IVB Separate, Abort; 0 = TRUE
 */
#define CH030_SIVB_SEPARATE_ABORT       BIT4

/**
 * LIFTOFF DISCRETE, 0 = TRUE
 */
#define CH030_LIFTOFF       BIT5

/**
 * GUIDANCE REFERENCE RELEASE, 0 = TRUE
 */
#define CH030_GRR       BIT6

/**
 * IMU Operate; 0 = TRUE
 */
#define CH030_IMU_OPERATE   BIT9

/**
 * Spacecraft control of Saturn L/V; 1 = IU Control, 0 = S/C Control
 */
#define CH030_SC_CONTROL    BIT10

/**
 * ISS Turn on Request; 0 = TRUE
 */
#define CH030_ISS_TURN_ON_REQUEST    BIT14

/**
 * ISS Temp in limits; 0 = TRUE
 */
#define CH030_ISS_TEMP_IN_LIMITS    BIT15

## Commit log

2020-08-20 Add fasteners BOM
    [fasteners-bill-of-materials.csv]
2020-08-29 small tweaks for alarm driver test
2020-10-03 move Keycap STL file
    [Keycap.stl]
2020-11-11 Add a couple of new photos
2020-11-15 Add new images and a few 3D print-optimized parts
    [1006350A-3dprint-GASKET, RETAINED.f3d, 1006350A-Left-half.stl, 1006350A-Right-half.stl]
2020-11-15 revise insert hole size for #4-40
2020-11-15 Added two components; one optimized for screw inserts
    [1006351A-exact-GASKET.f3d, 1006351A-exact-GASKET.step, 2004919E-inserts-PLATE, ADAPTER.step]
2020-12-06 first cut at an untested virtual agc-based driver
2021-01-19 Update README to include basic Arduino build information
2021-01-20 Deeper instructions on board configuration
2021-02-27 Add revised keycaps base model, gasket model, backlit key photo
    [1006349-3dprint-GASKET, RETAINED.f3d, 1006349-Left-half.stl, 1006349-Right-half.stl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]
2021-02-28 add LED Display module
2021-10-10 add Pi-Power PCB
2021-10-11 add LED variant block diagram
2021-10-21 Update status and addition of Pi-Power PCB
2021-10-24 Add mounting components and base
    [left-base.step, pi-mount.step, right-base.step]
2021-10-25 Add Hardware parts BOM
2021-10-25 BOM image
2021-10-25 Update Parts BOM
2021-10-25 Update BOM table
2021-10-31 Switch relay sound file to mono
2021-11-06 Update inserts used on front cover
2021-11-20 Add 2004929 Front Cover, update FDAI texture to use Groton font
    [2004929-exact-COVER, FRONT.step]
2021-11-20 Update 4-40 holes for Grainger 1GPL4 inserts
2021-11-20 Shorten keycap base to make keys flush with cover
    [Keycap-base.step, Keycap-base.stl]
2023-01-17 Add supplemental documentation on 3D printing and a starter BOM.
2023-01-18 Add fasteners.csv from downloaded McMaster/Carr data
    [fasteners.csv]
2023-01-22 add 2004968 - front housing
2023-01-23 add revised front cover - with dowel pin holes
    [2004929-exact-COVER, FRONT.step]
2023-02-14 update FRONT HOUSING to clean up back and a couple of holes
2023-02-15 Update Raspberry Pi mounting bracket for improved back PCB clearance
    [pi-mount.step]
2023-02-18 Update Pi-Power
2025-04-01 KiCad 9

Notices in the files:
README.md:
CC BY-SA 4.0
